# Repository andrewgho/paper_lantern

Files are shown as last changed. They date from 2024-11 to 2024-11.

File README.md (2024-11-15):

Paper lantern flashlight diffuser
=================================

This is a set of 3D printable objects which turn a flashlight and a cheap
paper lantern into a beautiful room light that is easy to travel with.

Description
-----------

Light quality (a relaxing color temperature and high color rendering) is very
important for my mood and well-being. At home, I have many small lamps with
very warm LED bulbs or with low-wattage incandescent or halogen bulbs. But,
when traveling, even the most luxurious hotel or AirBnB may have lighting
which is cold, harsh, or too bright. When it is evening, I want my residence
to be cozy and welcoming.

As a flashlight geek (this is you if you browse
[/r/flashlight](https://www.reddit.com/r/flashlight) or
[BLF](https://budgetlightforum.com/)), I usually travel with a
[Lumintop FW3A](https://lumintop.com/product/fw3a/) with LED emitters that are
very warm (2700K) and have a high color rendering index (95 CRI).

This set of 3D printable objects is a flashlight diffuser that snaps on to a
flashlight and mates it with a
[cheap (USD $1) paper lantern](https://www.amazon.com/gp/product/B0CWXCNL94)
which can collapse flat for packing, creating a portable room lighting
solution that is as high quality as whatever flashlight you already own.

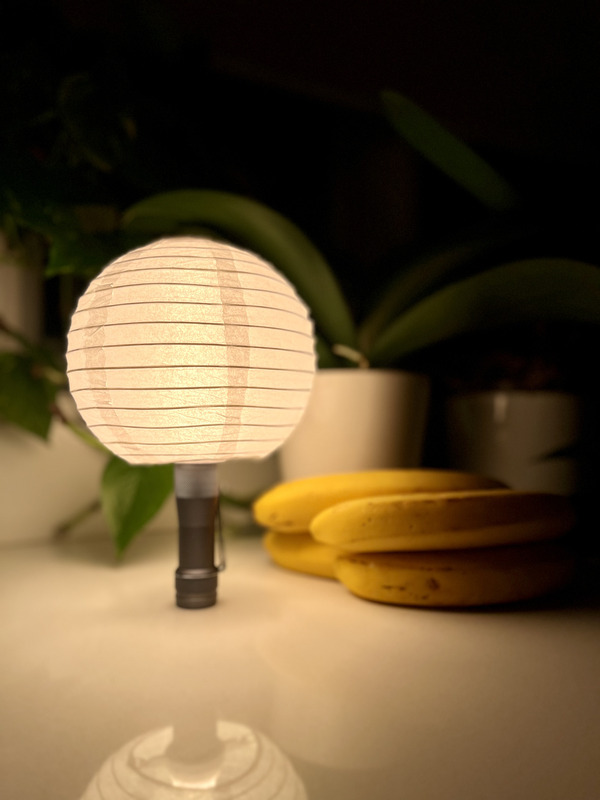
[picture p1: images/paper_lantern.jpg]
Paper flashlight lantern on kitchen counter


The diffuser friction-fits on the flashlight, has a hat on top to prop the top
of the lantern open, and has a spacer collar on the bottom which hooks onto
the wire hoops that most paper lanterns have.

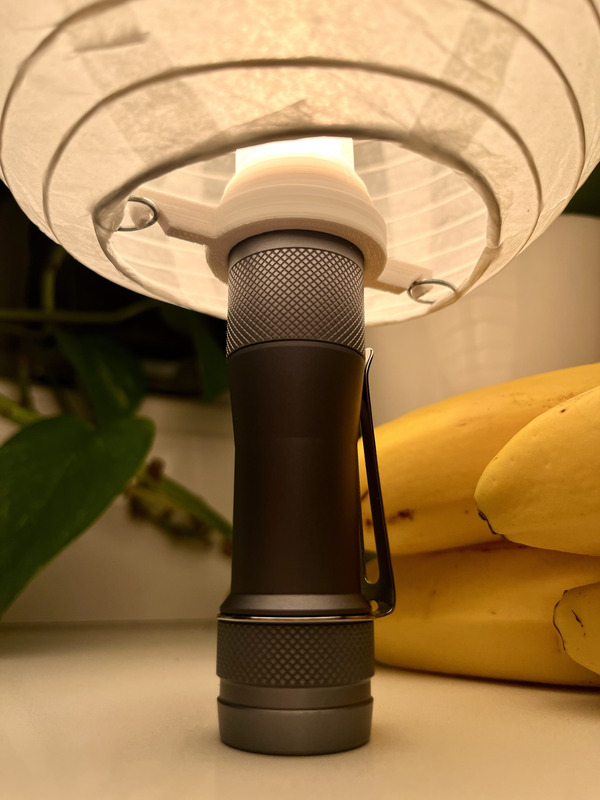
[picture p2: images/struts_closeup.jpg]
Bottom detail showing paper lantern struts


All the parts other than the diffuser tube are flat for easy packing. I put
them all into a one-quart zipper bag (I lock out the flashlight and separately
clip it to an exterior pocket of my carry-on personal item):

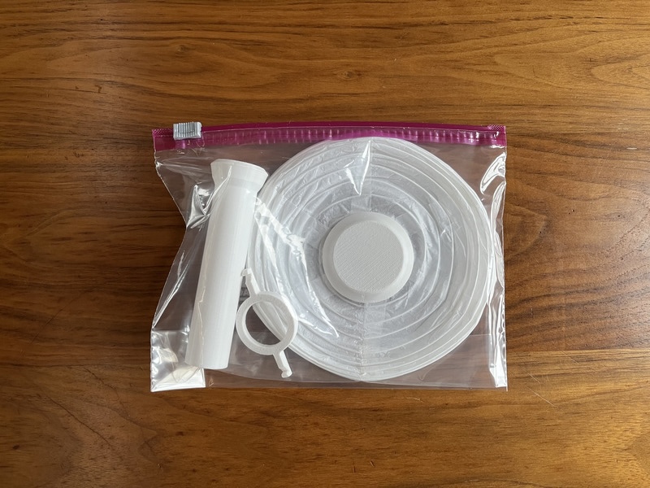
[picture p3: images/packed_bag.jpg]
Parts packed into quart zipper bag


With this setup, I can turn off any harsh room lighting in the hotel or AirBnB
and enjoy beautiful warm light that I brought with me.

### Parts

Aside from the printed parts, you need a 6" round paper lantern and a
flashlight. You can purchase the lantern from Amazon (for example, the
[LIHAO 6 Inch White Round Paper Lantern](https://www.amazon.com/gp/product/B0CWXCNL94)
is around USD $9 for a 10-pack, search for
["6 inch paper lantern"](https://www.amazon.com/s?k=6+inch+paper+lantern)),
or for under USD $1 each from
[PaperLanternStore](https://www.paperlanternstore.com/collections/6-round-paper-lanterns/products/6-white-round-paper-lantern-even-ribbing).
If you prefer to support a local retailer, you may be able to find this at a
craft or party supply store. If you are not using the LIHAO paper lantern,
you may need to adjust the `top_diameter` parameter in the OpenSCAD to fit
the top aperture of the paper lantern.

The flashlight the 3D model is designed for is the
[Lumintop FW3A](https://lumintop.com/product/fw3a/), which has a 25.5mm outer
diameter cylindrical head. Any flashlight with enough cylindrical space at
the head (an inexpensive Convoy S2+ for example) would also work. If you
are using a different light, or your printer tolerances are different, you
may need to adjust the `light_diameter` parameter in the OpenSCAD source
(I had to print with this set to 25.8mm).

The included G-Code is for a Prusament brand PETG with the Original Prusa MINI
printer, with a 0.15mm layer height; unless you have this exact configuration,
you will want to reslice from the STL file. All the parts print cleanly with
no supports, although your slicer may recommend a brim for the spacer collar.
My printer lives in a room that is not perfectly dry, so I get some stringing
with PETG, and printing the diffuser tube by itself seems to yield better
results than printing all parts separately.

### Assembly

First print and collect the parts (you can discard any metal hanging frame
that comes with the paper lantern):

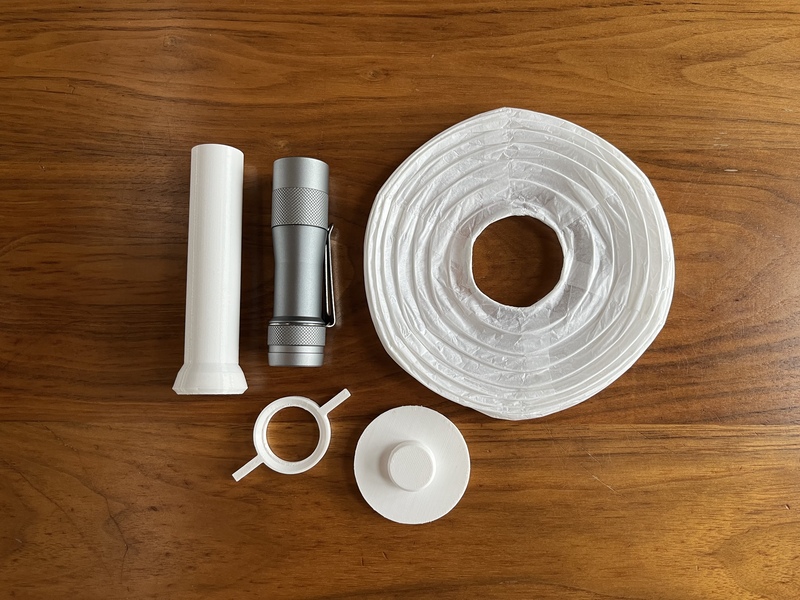
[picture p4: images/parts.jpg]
Lantern parts laid out on table


Snap together, in order, the spacer collar ring, with the notches facing
downwards; the diffuser tube; and the hat:

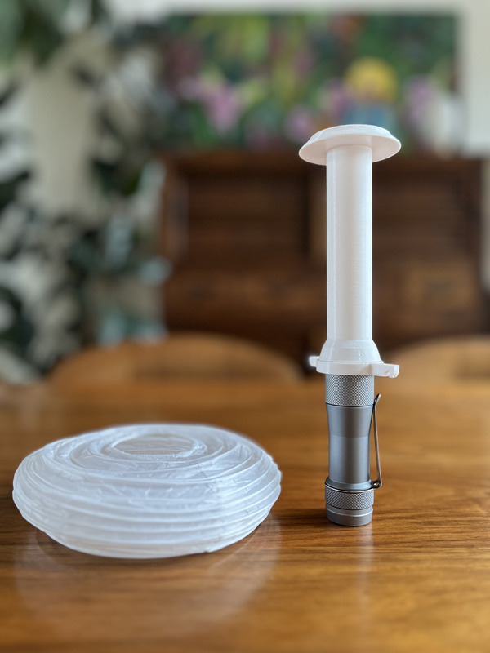
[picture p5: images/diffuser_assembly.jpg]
Collapsed paper lantern next to assembled diffuser


Most paper lanterns have metal hoops at the bottom (larger) aperture. Insert
the diffuser and hat into the bottom aperture, push the top of the hat into
the upper (smaller) aperture, and then hook the metal hoops into the spacer
collar notches.

To disassemble, it is usually easiest to unhook the metal hoops first, so you
can move the delicate lantern out of the way.

### Related

There are some very nice commercially available rechargeable lanterns, even
ones with paper shades, such as these
[TOCHIN](https://www.instagram.com/torchin__/) (sometimes spelled "TORCHIN")
lanterns sold in Japan:

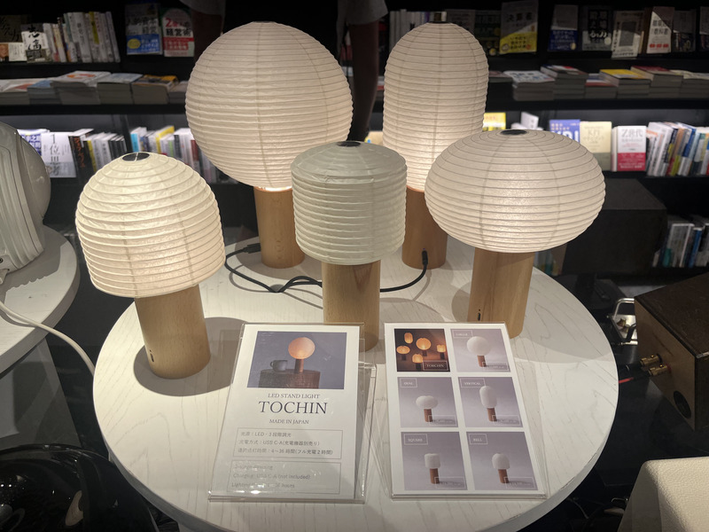
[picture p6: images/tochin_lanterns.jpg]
TOCHIN lanterns on display in Japanese store


This is a great product, with a beautiful wooden base, but it is very
expensive (over USD $200), doesn't collapse for packing, and is quite
fragile—the paper diffuser is fixed in place and not user replaceable.

There is an awesome open-source 3D printable
[Diffuser Lamp and Base for Emisar Lights](https://www.printables.com/model/836266-diffuser-lamp-and-base-for-emisar-lights)
made by [@Spicy3d](https://spicy3dprints.com/) which I have traveled with
before):

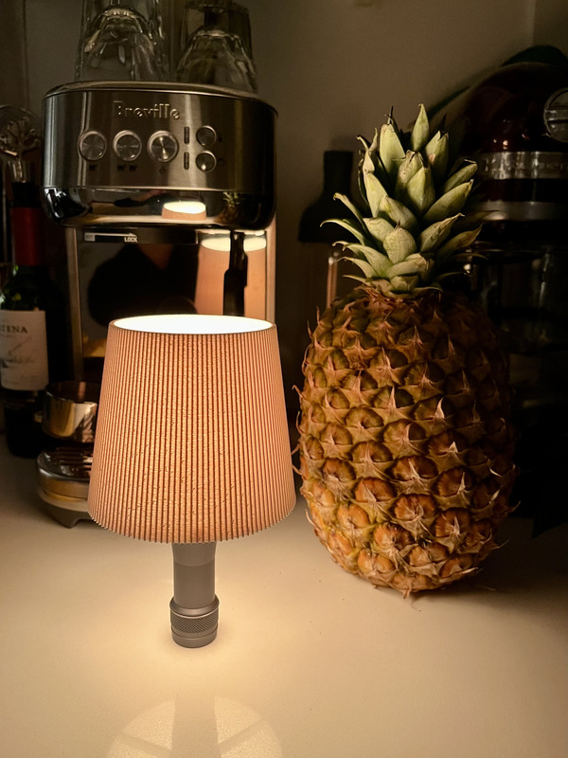
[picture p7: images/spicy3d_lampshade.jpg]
Spicy3d designed one piece diffuser lampshade


I love this lampshade (it's so cute!), and have carried it on road trips where
I didn't have to worry about luggage space; but it is tricky to pack (takes up
a lot of room, and can be a bit fragile unless you can print it in ABS).

This project is also listed on [Printables](https://www.printables.com):
[Paper lantern flashlight diffuser on Printables](https://www.printables.com/model/1074651-paper-lantern-flashlight-diffuser)

Author
------

Andrew Ho (<andrew@zeuscat.com>)

License
-------

Copyright© 2024 Andrew Ho.
Licensed under
[CC BY 4.0](https://creativecommons.org/licenses/by/4.0/).

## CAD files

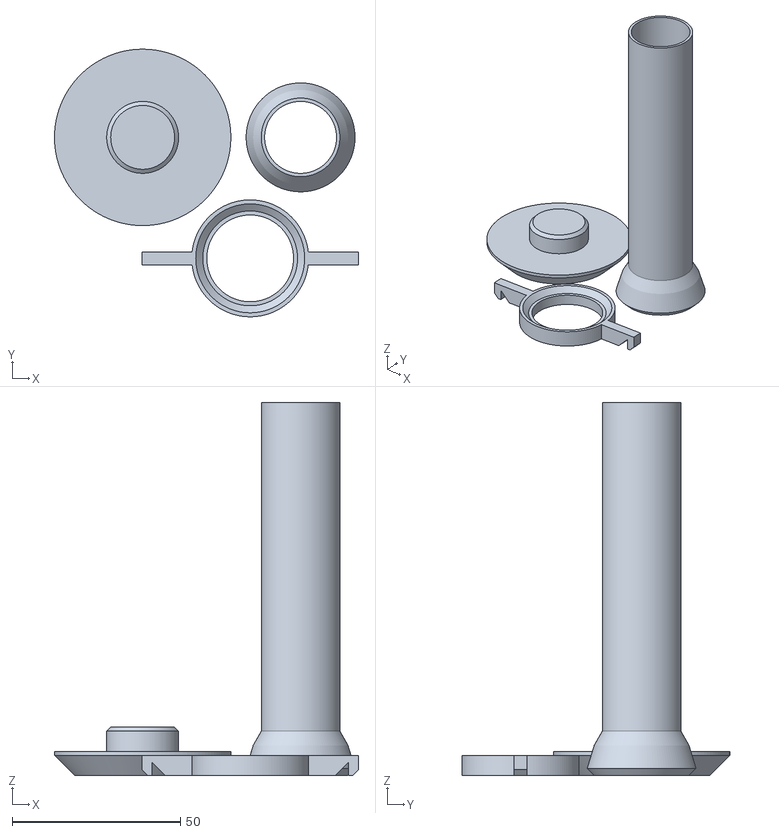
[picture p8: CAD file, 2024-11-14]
paper_lantern.stl
90.5 x 79.7 x 111.0

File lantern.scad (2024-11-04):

// lantern.scad - paper lantern scaffolding for FW3A flashlight
// Andrew Ho <andrew@zeuscat.com>

shade_diameter  =   6.0 * 25.4;  // Interior diameter of lampshade sphere
shade_height    = 109.2;         // Height from bottom supports to top opening
top_diameter    =  40.5;         // Diameter of top opening
light_diameter  =  25.6;         // Exterior diameter of flashlight head
lip_height      =   9.0;         // How far down the diffuser sits on the head
shrink_radius   =   2.1;         // How far inward to shrink the diffuser
flange_height   =   2.1;         // Vertical height of 45° bottom flange
spacer_height   =   6.0;         // Height of spacer spanning the wire posts
spacer_width    =   3.9;         // Hull thickness of spacer
bottom_post_gap =  58.5;         // Gap between wire posts on bottom support
wire_thickness  =   0.95;        // How thick the bottom support post wire is
thickness       =   1.2;         // Default wall thickness

// Correction factors
light_correction = 0.2;  // Add to flashlight diameter

e = 0.1;
e2 = e * 2;
thickness2 = thickness * 2;
$fn = 120;

// Top piece, which holds top of paper lantern taut
module hat() {
  // The flat plug that rests against top aperture of the paper lantern
  hull() {
    cylinder(d = top_diameter, h = e);
    translate([0, 0, thickness * 5]) {
      cylinder(d = top_diameter + (thickness * 10), h = thickness);
    }
  }
  // The flashlight shaft equivalent that the diffuser snaps into
  d = light_diameter - (shrink_radius * 2);
  h = (lip_height * 0.8);
  hull() {
    translate([0, 0, thickness * 6]) {
      cylinder(d = d, h = h - thickness);
      translate([0, 0, h - thickness]) {
        cylinder(d = d - thickness2, h = thickness);
      }
    }
  }
}

// Middle shaft, which is the vertical support and attaches to the flashlight
module diffuser() {
  // Lip of the diffuser, or the part which sits on the flashlight head
  lip_id = light_diameter + light_correction;
  lip_od = lip_id + thickness2;
  lip_flange_od = lip_od + (2 * flange_height);
  difference() {
    union() {
      cylinder(d1 = lip_od, d2 = lip_flange_od, h = flange_height);
      translate([0, 0, flange_height]) {
        cylinder(d1 = lip_flange_od, d2 = lip_od, h = lip_height - flange_height);
      }
    }
    translate([0, 0, -e]) cylinder(d = lip_id, h = lip_height + e2);
  }
  // Main cylindrical shaft above the flashlight
  t = 1.0;
  t2 = t * 2;
  shaft_id = light_diameter - (shrink_radius * 2);
  shaft_od = shaft_id + t2;
  shaft_height = shade_height - (thickness * 6);  // TODO: calculate better
  belt_height = shrink_radius * 2;
  translate([0, 0, lip_height]) {
    difference() {
      union() {
        cylinder(d1 = lip_od, d2 = shaft_od, h = belt_height);
        translate([0, 0, belt_height]) {
          cylinder(d = shaft_od, h = shaft_height - belt_height);
        }
      }
      union() {
        translate([0, 0, -e]) cylinder(d = lip_id, h = e2);
        cylinder(d1 = lip_id, d2 = shaft_id, h = belt_height);
        translate([0, 0, belt_height - e]) {
          cylinder(d = shaft_id, h = (shaft_height - belt_height) + e2);
        }
      }
    }
  }
}

// Coupler which attaches to the wire loops at the bottom of the lantern
module spacer() {
  id = light_diameter + light_correction + thickness2;
  od = id + thickness2;
  flange_od = od + (2 * flange_height);
  spacer_length = bottom_post_gap + spacer_height;

  module wire_notch() {
    h = spacer_height * 0.66;
    translate([-h, (spacer_width / 2) + e, 0]) {
      rotate(90, [1, 0, 0]) {
        linear_extrude(spacer_width + e2) {
          polygon([[0, -e], [0, 0], [h, h], [h, -e]]);
        }
      }
    }
  }

  difference() {
    union() {
      cylinder(d = flange_od, h = spacer_height);
      translate([-spacer_length / 2, -spacer_width / 2, 0]) {
        cube([spacer_length, spacer_width, spacer_height]);
      }
    }
    translate([0, 0, -e]) cylinder(d = id - thickness2, h = spacer_height + e2);
    translate([0, 0, spacer_height - flange_height]) {
      hull() {
        cylinder(d1 = id, d2 = id + (2 * flange_height), h = flange_height);
        translate([0, 0, flange_height]) {
          cylinder(d = id + (2 * flange_height), h = e);
        }
      }
    }
    translate([bottom_post_gap / 2, 0, 0]) {
      wire_notch();
      translate([(spacer_height * 0.66) + thickness, 0, 0]) wire_notch();
    }
    mirror([1, 0, 0]) {
      translate([bottom_post_gap / 2, 0, 0]) {
        wire_notch();
        translate([(spacer_height * 0.66) + thickness, 0, 0]) wire_notch();
      }
    }
  }
}

module visual() {
  difference() {
    union() {
      translate([0, 0, shade_height + 10]) hat();
      diffuser();
      translate([0, 0, -(spacer_height + 1)]) spacer();
    }
  }
}

module printable() {
  hat();
  translate([47, 0, 0]) diffuser();
  translate([32, -36, 0]) spacer();
}

printable();

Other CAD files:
paper_lantern.scad

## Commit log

2024-10-06 Initial repository creation
    [lantern.scad, lantern.stl]
2024-10-06 Change hat to simple flat design, fix wire notches, add light correction factor
    [lantern.scad, lantern.stl]
2024-10-07 Fix top shaft diameter, aperture diameter; print full size diffuser shaft
    [lantern.scad, lantern.stl]
2024-10-07 Shorten/narrow diffuser shaft, tighten fit, increase spacer strength
    [lantern.scad, lantern.stl]
2024-10-12 Add A-frame variant
    [aframe.scad, aframe.stl]
2024-10-12 Make various revisions to A-frame design
    Narrow top opening, again (sigh). Fix bottom post length and add actual posts.
    Slightly widen flashlight head size. Make collet more pleasingly rounded.
    Add a small correction gap for to make part fit more realistic. Add both
    visual (blowup diagram) and printable (parts flat) variants.
    [aframe.scad, aframe.stl]
2024-11-04 Abandon A-frame design
    [aframe.scad, aframe.stl]
2024-11-04 Resize for paper (not nylon) lantern, loosen diffuser shaft
    [lantern.scad, lantern.stl]
2024-11-14 Rename project and add README skeleton
    [lantern.stl, paper_lantern.scad, paper_lantern.stl]
2024-11-14 Add license
    [paper_lantern.scad]
2024-11-15 Add print and assembly instructions
2024-11-15 Add Printables link
